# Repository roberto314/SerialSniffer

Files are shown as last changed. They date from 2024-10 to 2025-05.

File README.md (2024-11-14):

# SerialSniffer
A Board to to observe serial communication between two units.

Version 1.0

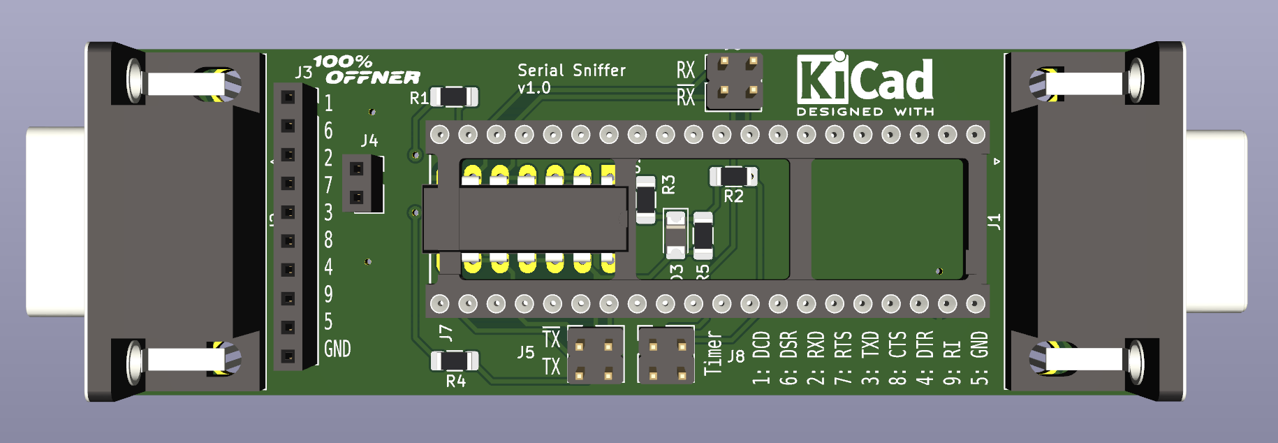
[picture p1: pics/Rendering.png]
kicad Rendering


This is a small PCB with a STM32F401 "blackpill" Board ontop. It can measure the Baudrate with a timer and then switch to listen mode and relay the packets via USB to the host computer.

There are two hardware serial ports on the STM32 and one USB for shell and output.

Firmware is ChibiOS Link: https://www.chibios.org), Version is trunk from ChibiStudio 20. Compilation is done with ChibiStudio 20 on Linux.

### Usage ###

* Connect a USB Cable to the "blackpill" Board,
* Start a terminal (i use picocom - "picocom /dev/ttyACM0")
* press "ENTER" a shell prompt should appear: Serial_Sniffer>
* enter "help" to get a list of all commands
* connect the Jumper J8 (marked "Timer") to one of the channels
* when communication occurs there should be a "Baud: abcd" outpt at the console
* enter the Baudrate with "sbr abcd" and switch on the listeners with "son 1"

There are some Jumpers on the board. J3 and J4 and the solder Jumper on the back JP2 and JP3 lets you connect to different Pins of the DB-9 connector for non-standard pinouts. The Jumper Pin5 is for Ground which is usually on Pin5.

### Used Software and OS ###

* Linux Mint (21.3 cinnamon) (Link: https://linuxmint.com/)
* Sublime Text 3 (Link: https://www.sublimetext.com/)
* Chibi Studio 20 (IDE for ChibiOS) (Link: https://www.chibios.org/dokuwiki/doku.php?id=chibios:products:chibistudio:start)

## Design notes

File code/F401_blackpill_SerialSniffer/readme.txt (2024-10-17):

*****************************************************************************
** ChibiOS/RT port for ARM-Cortex-M4 STM32F407.                            **
*****************************************************************************

** TARGET **

The demo runs on an STM32F411 or STM32F401 blackpill board.
(25MHz Crystal)
Serial Port over USB (also Debug Interface).
Serial 115200 Bd

Build:
Build with eclipse or simply type "make" in the code folder.

-----------------   WORK in Progress

Functions:

Pinout:
PA0  - KEY Button
PA1  - free
PA2  - TX2 (listener 2)
PA3  - RX2 (listener 2)
PA4  - free
PA5  - free
PA6  - free
PA7  - free
PA8  - free
PA9  - TX1 (listener 1)
PA10 - RX1 (listener 1)
PA11 - USD DM (Ostrich)
PA12 - USB DP (Ostrich)
PA13 - SWDIO
PA14 - SWCLK
PA15 - free

PB0  - free
PB1  - free
PB2  - free
PB3  - free
PB4  - free
PB5  - free
PB6  - free
PB7  - free
PB8  - free
PB9  - free
PB10 - free

PB12 - free
PB13 - free
PB14 - free
PB15 - free

PC13 - LED
PC14 - Debug
PC15 - Debug

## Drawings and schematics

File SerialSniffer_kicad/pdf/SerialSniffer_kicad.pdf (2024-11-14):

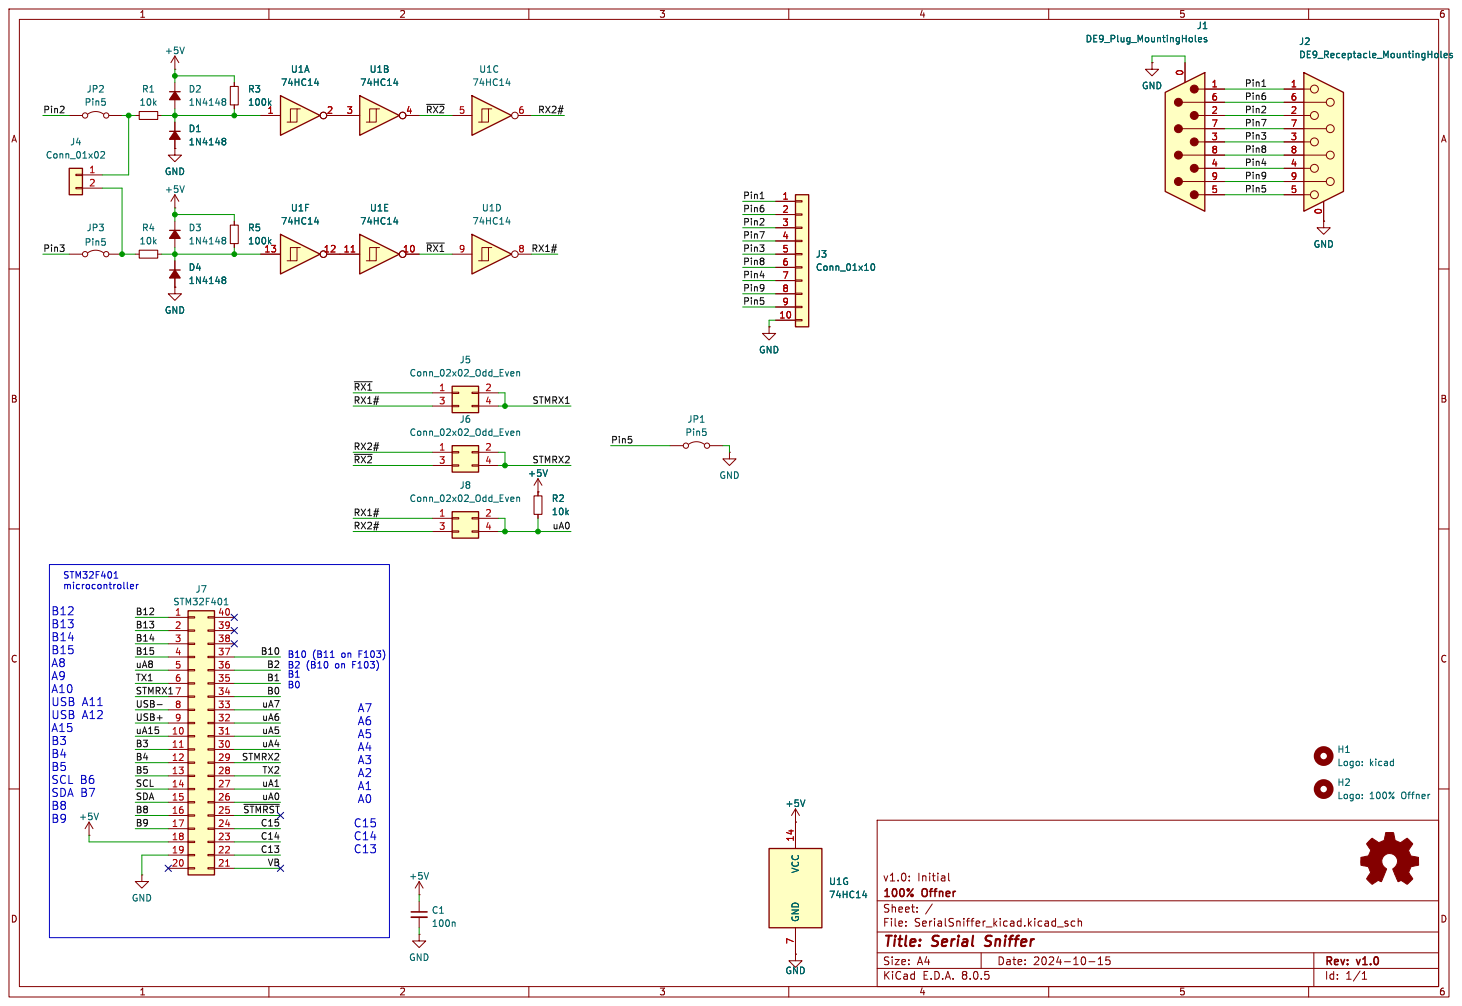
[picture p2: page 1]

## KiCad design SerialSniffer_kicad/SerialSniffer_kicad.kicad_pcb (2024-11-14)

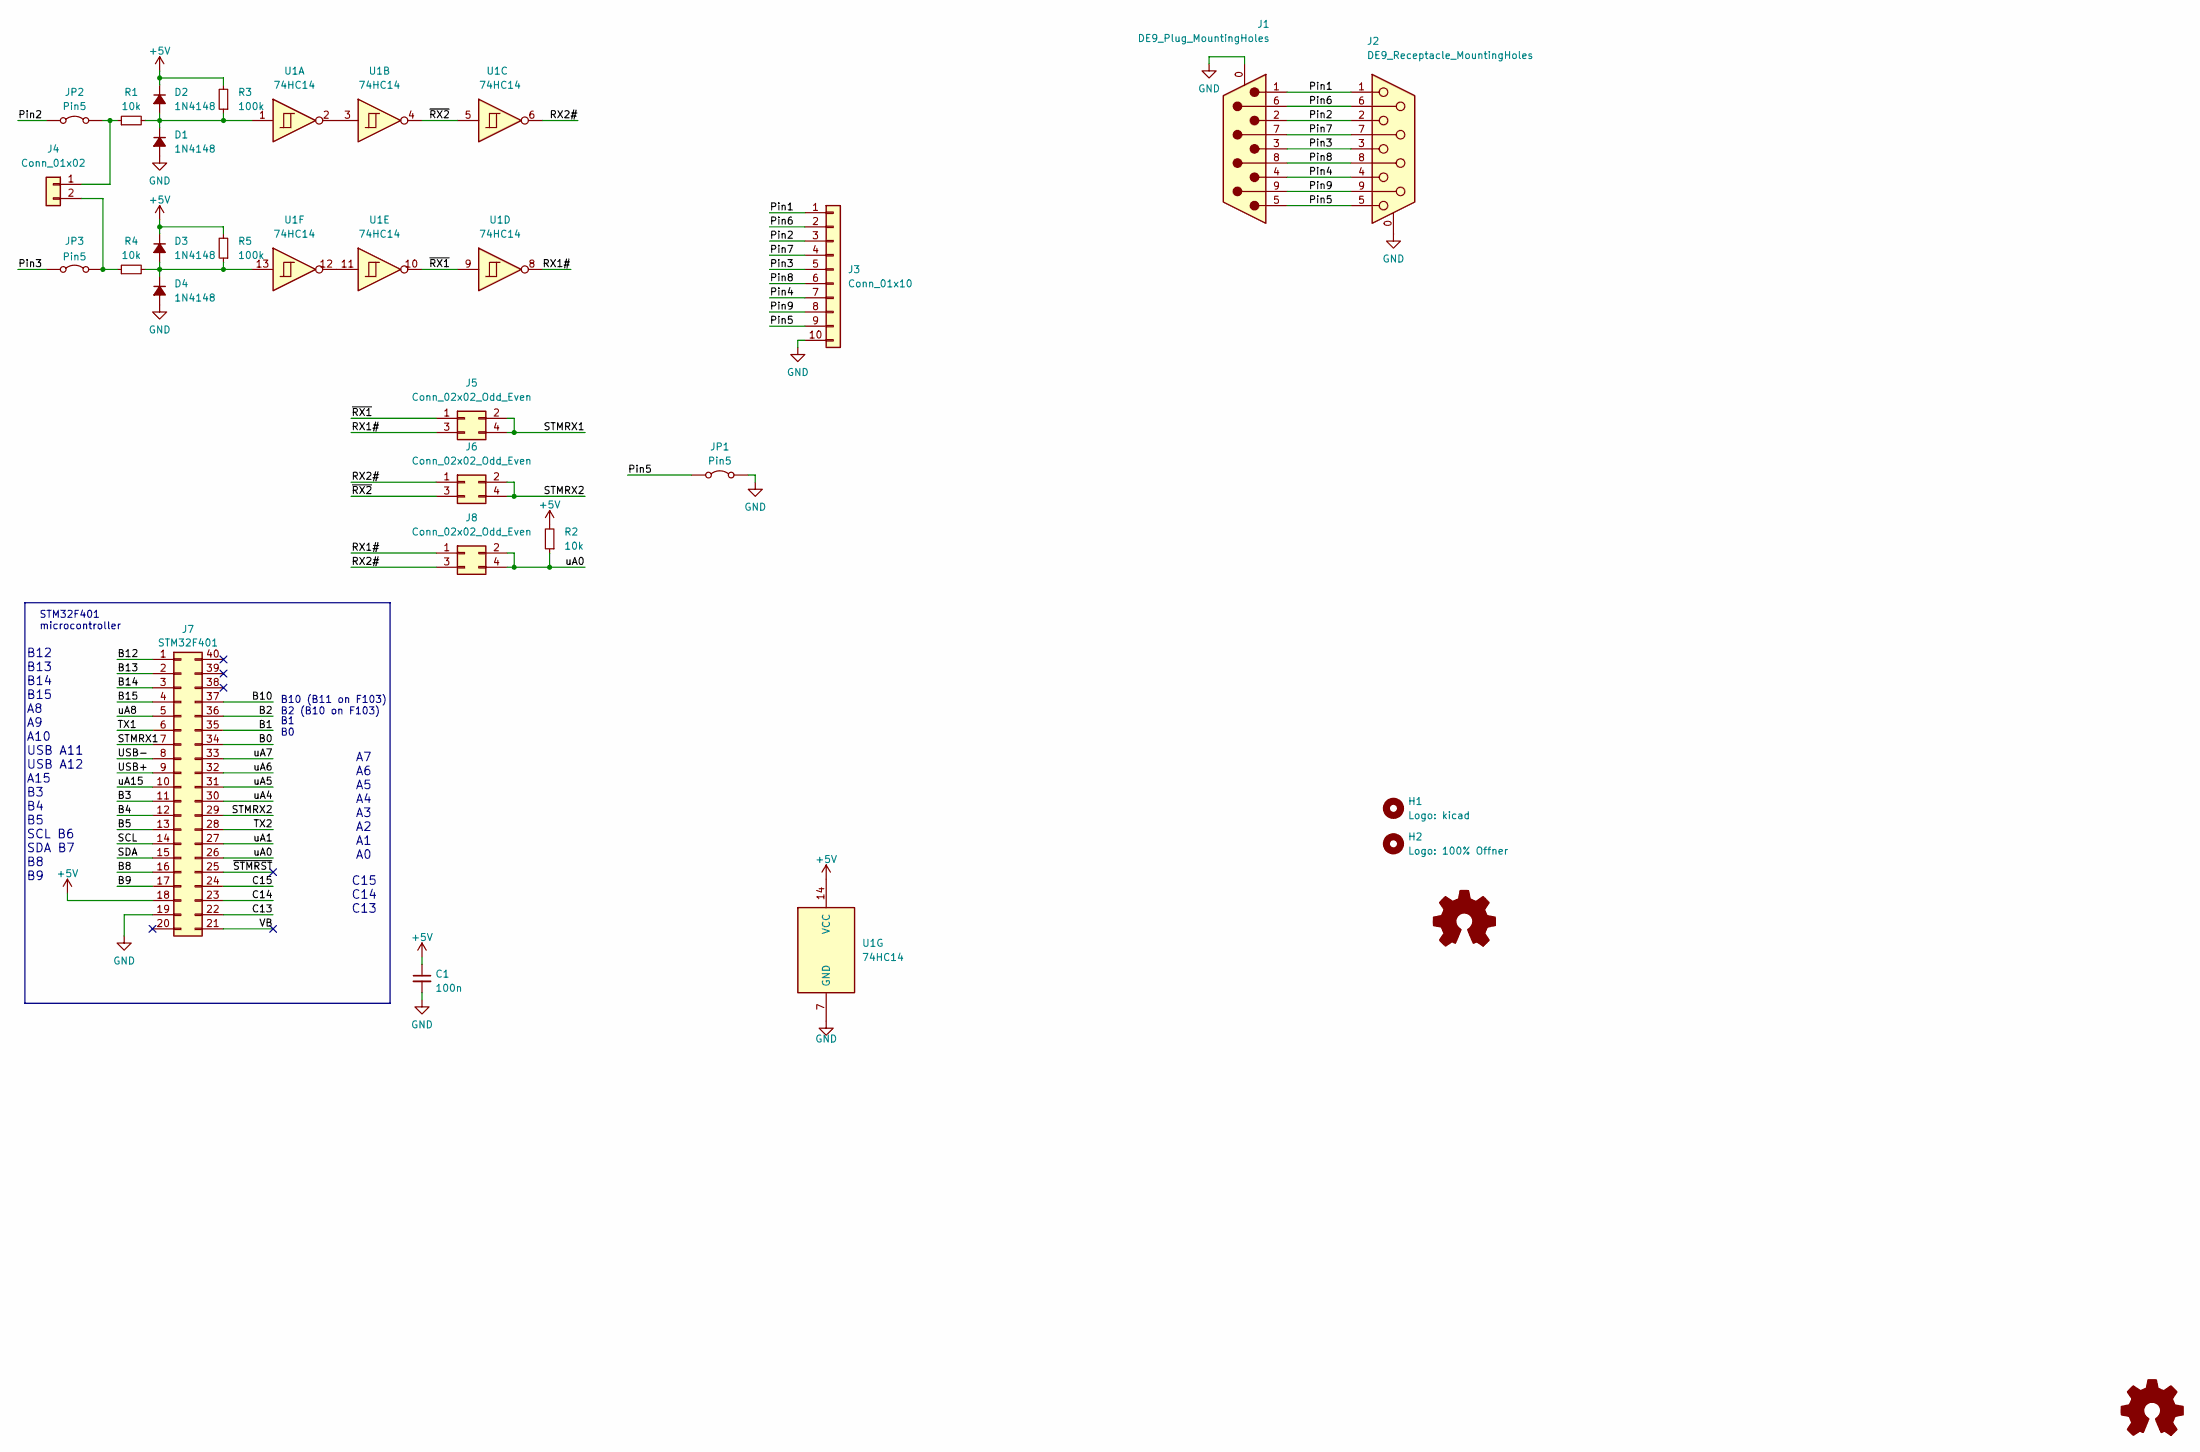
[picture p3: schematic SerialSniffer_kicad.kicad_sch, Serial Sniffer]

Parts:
C1: 100n; C_1206_3216Metric
D1, D2, D3, D4: 1N4148; D_1206_3216Metric_Pad1.42x1.75mm_HandSolder
H1: Logo: kicad; KiCad-Logo2_5mm_SilkScreen
H2: Logo: 100% Offner; Logo_100ProzentOffner_10x2.7mm
J1: DE9_Plug_MountingHoles; DSUB-9_Female_Horizontal_P2.77x2.84mm_EdgePinOffset7.70mm_H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
J2: DE9_Receptacle_MountingHoles; DSUB-9_Male_Horizontal_P2.77x2.84mm_EdgePinOffset7.70mm_Hou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
J3: Conn_01x10; PinSocket_1x10_P2.54mm_Vertical
J4: Conn_01x02; PinSocket_1x02_P2.54mm_Vertical
J5, J6, J8: Conn_02x02_Odd_Even; PinHeader_2x02_P2.54mm_Vertical
J7: STM32F401; DIP-40_W15.24mm_Socket_LongPads
JP1, JP2, JP3: Pin5; SolderJumper-2_P1.3mm_Bridged_RoundedPad1.0x1.5mm
R1, R2, R4: 10k; R_1206_3216Metric_Pad1.30x1.75mm_HandSolder
R3, R5: 100k; R_1206_3216Metric_Pad1.30x1.75mm_HandSolder
U1: 74HC14; DIP-14_W7.62mm_LongPads

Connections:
+5V: C1.1, D2.1 (K), D3.1 (K), J7.18, R2.2, R3.2, R5.2, U1.14 (VCC)
/B0: J7.34
/B1: J7.35
/B2: J7.36
/B3: J7.11
/B4: J7.12
/B5: J7.13
/B8: J7.16
/B9: J7.17
/B10: J7.37
/B12: J7.1
/B13: J7.2
/B14: J7.3
/B15: J7.4
/C13: J7.22
/C14: J7.23
/C15: J7.24
/Pin1: J1.1, J2.1, J3.1
/Pin2: J1.2, J2.2, J3.3, JP2.2 (B)
/Pin3: J1.3, J2.3, J3.5, JP3.2 (B)
/Pin4: J1.4, J2.4, J3.7
/Pin5: J1.5, J2.5, J3.9, JP1.1 (A)
/Pin6: J1.6, J2.6, J3.2
/Pin7: J1.7, J2.7, J3.4
/Pin8: J1.8, J2.8, J3.6
/Pin9: J1.9, J2.9, J3.8
/RX1#: J5.3, J8.1, U1.8
/RX2#: J6.1, J8.3, U1.6
/SCL: J7.14
/SDA: J7.15
/STMRX1: J5.2, J5.4, J7.7
/STMRX2: J6.2, J6.4, J7.29
/TX1: J7.6
/TX2: J7.28
/USB+: J7.9
/USB-: J7.8
/VB: J7.21
/uA0: J7.26, J8.2, J8.4, R2.1
/uA1: J7.27
/uA4: J7.30
/uA5: J7.31
/uA6: J7.32
/uA7: J7.33
/uA8: J7.5
/uA15: J7.10
/~RX1: J5.1, U1.9, U1.10
/~RX2: J6.3, U1.4, U1.5
/~STMRST: J7.25
GND: C1.2, D1.2 (A), D4.2 (A), J1.0 (PAD), J2.0 (PAD), J3.10, J7.19, JP1.2 (B), U1.7 (GND)
unnamed: D1.1 (K), D2.2 (A), R1.2, R3.1, U1.1
unnamed: D3.2 (A), D4.1 (K), R4.2, R5.1, U1.13
unnamed: J4.1, JP2.1 (A), R1.1
unnamed: J4.2, JP3.1 (A), R4.1
unnamed: U1.2, U1.3
unnamed: U1.11, U1.12

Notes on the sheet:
B1 B0
B10 (B11 on F103) B2 (B10 on F103)
A7 A6 A5 A4 A3 A2 A1 A0
B12 B13 B14 B15 A8 A9 A10 USB A11 USB A12 A15 B3 B4 B5 SCL B6 SDA B7 B8 B9
C15 C14 C13
STM32F401 microcontroller

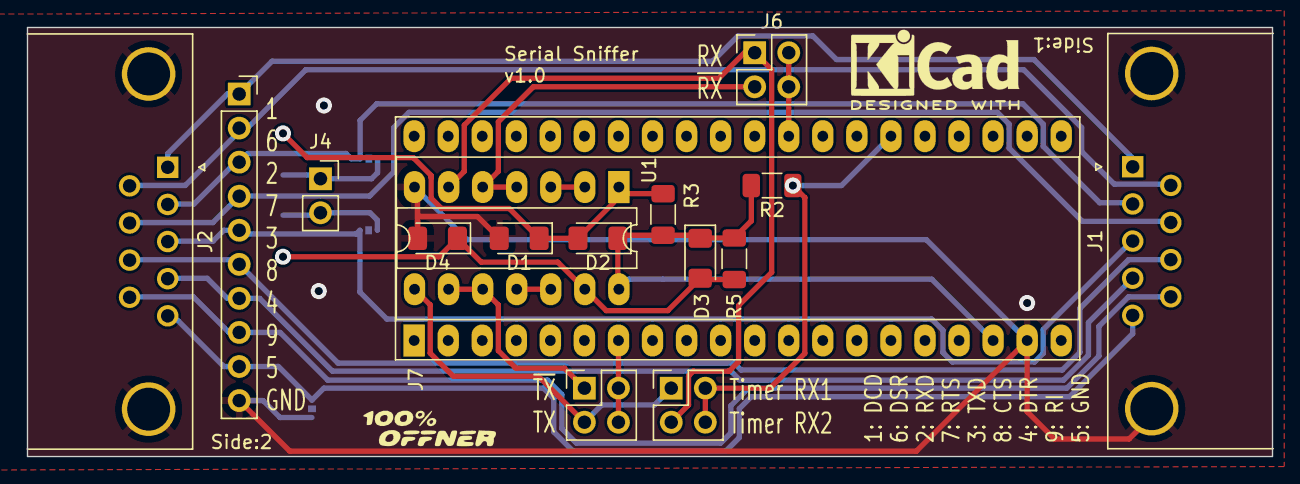
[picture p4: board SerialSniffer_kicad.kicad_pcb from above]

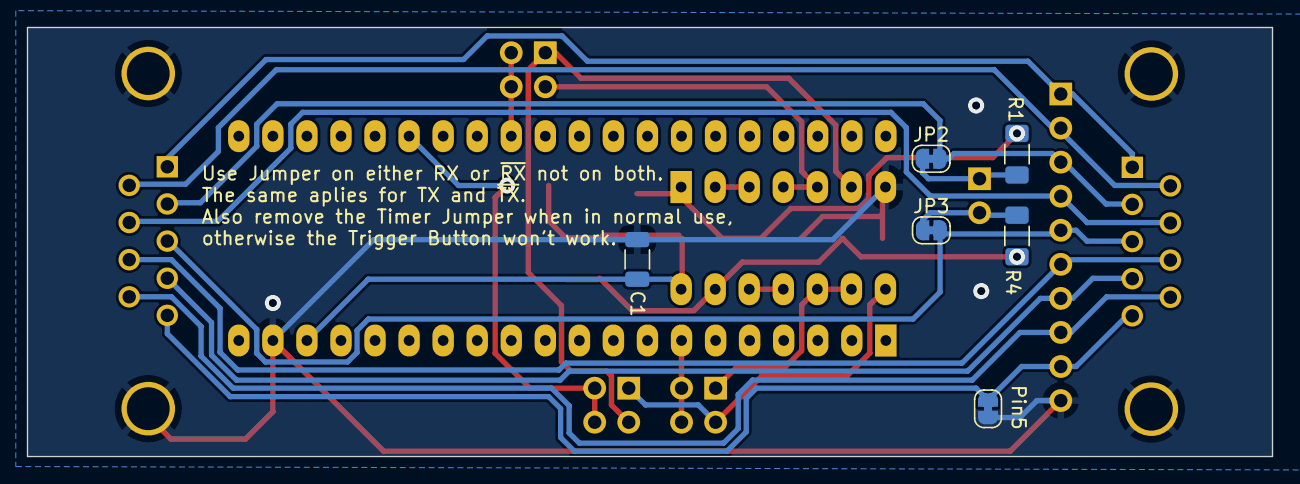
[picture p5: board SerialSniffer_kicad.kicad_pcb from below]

Board: 2 copper layers, 92.9 x 32.0 mm, 24 parts (6 on the bottom side), 24 nets.

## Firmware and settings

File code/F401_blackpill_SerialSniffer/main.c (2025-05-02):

/*
    ChibiOS - Copyright (C) 2006..2018 Giovanni Di Sirio

    Licensed under the Apache License, Version 2.0 (the "License");
    you may not use this file except in compliance with the License.
    You may obtain a copy of the License at

        http://www.apache.org/licenses/LICENSE-2.0

    Unless required by applicable law or agreed to in writing, software
    distributed under the License is distributed on an "AS IS" BASIS,
    WITHOUT WARRANTIES OR CONDITIONS OF ANY KIND, either express or implied.
    See the License for the specific language governing permissions and
    limitations under the License.
*/
#include "main.h"
#include "ch.h"
#include "hal.h"
#include <string.h>
#include <stdlib.h>
#include "portab.h"
#include "shell.h"
#include "chprintf.h"

#include "usbcfg.h"
#include "comm.h"

/*===========================================================================*/
/* Function Prototypes                                                       */
/*===========================================================================*/
void got_char(uint8_t c, uint8_t src);
uint32_t increase_rwcnt(uint32_t cnt);

/*===========================================================================*/
/* Global Variables                                                          */
/*===========================================================================*/
BaseSequentialStream *const shell = (BaseSequentialStream *)&SHELLPORT;
BaseSequentialStream *const dbg = (BaseSequentialStream *)&DEBUGPORT;

#define CLOCKFREQ 10000000UL
#define BUFFSZ 6000 

lst_st ldat[BUFFSZ];                // This is the Buffer
uint32_t write_cnt = 0, read_cnt = 0; // Indizes for Write and Read from Buffer
uint32_t rx_cnt = 0, tx_cnt = 0;
uint16_t flush_timeout = 1000;
uint8_t dump_format = 2, dump_in_progress = 0, first_char = 1;
systime_t fc_timestamp, last_received_char;

uint8_t serstat = 1; // 0: Serial off, Timer On
uint32_t smallest_pulse = 0xFFFF;
icucnt_t last_width1, last_period1;
uint32_t sp_temp;

/*===========================================================================*/
/* Button related code.                                                      */
/*===========================================================================*/

/* Function prototypes needed as the two callbacks call each other.
   there is no way to order the callback without triggering an error. */
static void button_cb(void *arg);
static void vt_cb(virtual_timer_t *vtp, void *p);
static uint8_t btn_second_edge = 0, btn_cnt = 0;

/* Virtual timer. */
static virtual_timer_t vt, vt2;

/* Callback of the virtual timer. */
static void vt_cb(virtual_timer_t *vtp, void *p) { // Timer cb after 50ms (single click)
  (void)vtp;
  (void)p;
  chSysLockFromISR();
  /* Enabling the event and associating the callback. */
  if (btn_second_edge) // The first edge is a negative one, the second a rising one
    palEnableLineEventI(EXTBTN, PAL_EVENT_MODE_RISING_EDGE); // Prepare for release of button
  else
    palEnableLineEventI(EXTBTN, PAL_EVENT_MODE_FALLING_EDGE);
  palSetLineCallbackI(EXTBTN, button_cb, NULL);
  chSysUnlockFromISR();
}

static void vt2_cb(virtual_timer_t *vtp, void *p) { // Timer cb after 200ms (double click)
  (void)vtp;
  (void)p;
  chSysLockFromISR();
  switch (btn_cnt){
  case 1:
    if (btn_second_edge){ // only for the first edge
      //chprintf(dbg, "click long. %d \r\n");
    }
    break;
  case 2:
    //chprintf(dbg, "click once. %d \r\n");
    got_char(' ', 3);
    break;
  default:
    //chprintf(dbg, "click double. %d \r\n");
    break;
  }

  btn_cnt = 0;
  chSysUnlockFromISR();
}
/* Callback associated to the falling or rising edge of the button line. */
static void button_cb(void *arg) {
  (void)arg;
  //palToggleLine(LED);
  if (btn_second_edge){    // next edge
    btn_second_edge = 0;
  }
  else{                  // very first negative going edge or Button released
    btn_second_edge = 1;
    //chprintf(dbg, "click immediately. %d \r\n");
  }
  btn_cnt++;           // count edges
  chSysLockFromISR();
  /* Disabling the event on the line and setting a timer to
     re-enable it. */
  palDisableLineEventI(EXTBTN);
  /* Arming the VT timer to re-enable the event in 50ms. */
  chVTResetI(&vt);
  chVTDoSetI(&vt, TIME_MS2I(50), vt_cb, NULL);
  chVTResetI(&vt2);
  chVTDoSetI(&vt2, TIME_MS2I(200), vt2_cb, NULL);
  chSysUnlockFromISR();
}

/*===========================================================================*/
/* Character Write Function                                                  */
/*===========================================================================*/

void got_char(uint8_t c, uint8_t src){ // This function fills the Ringbuffer
  //int32_t temp;
  //temp = write_cnt-1; // last entry
  last_received_char = TIME_I2MS(chVTGetSystemTime()); // get Timestamp
  if (src == 3){
    chprintf(dbg, "------------------ BREAK @ T[ms]: %06d\r\n", last_received_char);
  }
  else{
    ldat[write_cnt].lastchar = c;
    ldat[write_cnt].src = src;
    ldat[write_cnt].timestamp = last_received_char;
    if ((rx_cnt+tx_cnt) <= 1){
      //first_char = 0;
      chprintf(dbg, "\r\n------------------------- START HERE ------------------------------\r\n");
      fc_timestamp = last_received_char; // very first character
    } 
    write_cnt = increase_rwcnt(write_cnt);
  }
}

/*
 * This callback is invoked when a character is received but the application
 * was not ready to receive it, the character is passed as parameter.
 */
static void rxchar1(UARTDriver *uartp, uint16_t c) {
  (void)uartp;
  (void)c;
  rx_cnt++;
  got_char((uint8_t)c, 1);
}

UARTConfig uart_cfg1 = {
  NULL,
  NULL,
  NULL,
  rxchar1,
  NULL,
  NULL,
  38400,
  0,  // CR1 
  0,  // CR2 
  0   // CR3
};

static void rxchar2(UARTDriver *uartp, uint16_t c) {
  (void)uartp;
  (void)c;
  tx_cnt++;
  got_char((uint8_t)c, 2);
}

UARTConfig uart_cfg2 = {
  NULL,
  NULL,
  NULL,
  rxchar2,
  NULL,
  NULL,
  38400,
  0,  // CR1 
  0,  // CR2 
  0   // CR3
};

/*===========================================================================*/
/* Baudrate Measurement related                                              */
/*===========================================================================*/

static void icuwidthcb1(ICUDriver *icup) { // This gets called every falling edge.

  last_width1 = icuGetWidthX(icup);
  palTogglePad(GPIOC, 14);
  //if (last_width1 < smallest_pulse)
  //  smallest_pulse = last_width1;
}

static void icuperiodcb1(ICUDriver *icup) { // This gets called every rising edge.

  last_period1 = icuGetPeriodX(icup);
  palTogglePad(GPIOC, 15);
  sp_temp = last_period1 - last_width1;
  if (sp_temp < smallest_pulse)
    smallest_pulse = sp_temp;
  //if ((last_period1 - last_width1) < smallest_pulse)
  //  smallest_pulse = (last_period1 - last_width1);
}

ICUConfig icucfg1 = {
  ICU_INPUT_ACTIVE_HIGH,
  CLOCKFREQ,                                    /* 10MHz ICU clock frequency.   */
  icuwidthcb1,
  icuperiodcb1,
  NULL,
  ICU_CHANNEL_1,
  0U,
  0xFFFFFFFFU
};

void flush_buffer(void){
  write_cnt = 0;
  read_cnt = 0;
  memset(ldat, 0, sizeof(ldat));
  chprintf(dbg, "RX Count: %d or 0x%04X\r\n", rx_cnt, rx_cnt);
  chprintf(dbg, "TX Count: %d or 0x%04X\r\n", tx_cnt, tx_cnt);
  chprintf(dbg, "Total Count: %d or 0x%04X\r\n",(tx_cnt+rx_cnt), (tx_cnt+rx_cnt));
  rx_cnt = 0;
  tx_cnt = 0;
}

/*===========================================================================*/
/* Command line related.                                                     */
/*===========================================================================*/

#define SHELL_WA_SIZE   THD_WORKING_AREA_SIZE(2048)

char history_buffer[8*64];
char *completion_buffer[SHELL_MAX_COMPLETIONS];

static const ShellCommand commands[] = {
  {"test",cmd_test},
  {"sbr",cmd_sbr},
  {"son",cmd_son},
  {"format",cmd_format},
  {"flush",cmd_flush},
  {"stt",cmd_stt},
  {NULL, NULL}
};

static const ShellConfig shell_cfg1 = {
  (BaseSequentialStream *)&SHELLPORT,
  commands,
  history_buffer,
  sizeof(history_buffer),
  completion_buffer
};

uint32_t calc_baud(uint32_t time){
  double baudf = 0;
  uint32_t baud, baudu, baudl;
  uint32_t sbr[] = {150,300,600,1200,2400,4800,9600,19200,38400,57600,115200,230400};
  uint8_t idx = 0;
  if (time == 0)
    return 0;
  baudf = (CLOCKFREQ/time);
  baudu = (uint32_t)(baudf * 1.09); // Window is +- 9%
  baudl = (uint32_t)(baudf / 1.09); // Window is +- 9%
  baud = (uint32_t)baudf;
  //chprintf(dbg, "baud: %d, time: %d\r\n", baud, time);
  if (baudu < sbr[0])
    return 0;
  if (baudl > sbr[11])
    return 0xFFFFFFFF;
  for (idx = 0;idx < 12; idx++){
    //chprintf(dbg, "sbrl: %d sbru: %d\r\n", sbrl[idx], sbru[idx]);
    if ((baudl < sbr[idx]) && (baudu > sbr[idx]))
      return sbr[idx];
  }
  return baud;
}

/*
 * Green LED blinker thread, times are in milliseconds.
 */
static THD_WORKING_AREA(waThread1, 128);
static THD_FUNCTION(Thread1, arg) {

  (void)arg;
  chRegSetThreadName("blinker");
  while (true) {
    systime_t time;
    time = serusbcfg1.usbp->state == USB_ACTIVE ? 250 : 500;
    palClearPad(GPIOC, 13);
    chThdSleepMilliseconds(time);
    palSetPad(GPIOC, 13);
    chThdSleepMilliseconds(time);
    if (smallest_pulse < 65535){
      //chprintf(dbg, "Time: %d \r\n", smallest_pulse);
      chprintf(dbg, "Baud: %d \r\n", calc_baud(smallest_pulse));
      smallest_pulse = 0xFFFF;
    }
    //chprintf(dbg, "LastWidth: %d \r\n", last_width1);
    //chprintf(dbg, "LastPeriod: %d \r\n", last_period1);
//    count++;
//    if (count == 10){
//      count = 0;
//      smallest_pulse = 0xFFFF;
//    }
  }
}

void safe_print(uint8_t c){  // print only printable characters
  if ((c > 0x1F) && (c < 128))
    chprintf(dbg, "%c", c);
  else
    chprintf(dbg, "%c",'.');    
}

uint32_t increase_rwcnt(uint32_t cnt){
  cnt++;
  if (cnt >= BUFFSZ) cnt = 0; // check for oerflow
  return cnt;
}

int32_t get_count(void){
/* Data in Array (c: Character, 1,2: Source, t: Timestamp)
* c2tc2tc2tc2tc1tc1tc2t
* Dump this  |
*        make CR
*            |Dump|
*              make CR
*              wait until a change in source or a timeout happens
*/
  uint32_t temp_cnt = read_cnt;
  uint8_t src, next;
  if (ldat[temp_cnt].src == 0) return -2; // no more data in array
  while (1) {
    src = ldat[temp_cnt].src;
    temp_cnt = increase_rwcnt(temp_cnt);
    next = ldat[temp_cnt].src;
    if (src != next){ // we have a change in source
      if (next == 0) return -1; // block not finished, wait for timeout
      else return (temp_cnt - read_cnt); // block is finished
    } 
  }
  //chprintf(dbg, "i: %d, SRC: %d NXT: %d\r\n", i, src, next);
  return -2;
}

void dump_data_0(uint32_t cnt){
  uint32_t i;
  uint8_t ch, src;
  systime_t tm, dt;

  src = ldat[read_cnt].src;
  chprintf(dbg, "%d->%d cnt: %d \r\n", src, (src==1?2:1), cnt);
  for (i=0;i<cnt;i++){ // go through all the characters
    ch = ldat[read_cnt].lastchar;
    src = ldat[read_cnt].src;
    ldat[read_cnt].src = 0; // delete for next round
    tm = ldat[read_cnt].timestamp - fc_timestamp; // tm starts at zero
    dt = ldat[read_cnt].timestamp - ldat[(read_cnt-1)].timestamp; // time difference 
    if (tm)
      chprintf(dbg, "%02X T: %06d dT: %04d\r\n", ch, tm, dt);
    else
      chprintf(dbg, "%02X T: %06d dT: ----\r\n", ch, tm);
    read_cnt = increase_rwcnt(read_cnt);
  }
  //chprintf(dbg, "\r\n");
  return;
}

void dump_data_1(uint32_t cnt){
  uint32_t i;
  uint8_t ch, src;
  systime_t tm;

  src = ldat[read_cnt].src;
  tm = ldat[read_cnt].timestamp - fc_timestamp; // tm starts at zero
  chprintf(dbg, "%d->%d cnt: %d T: %06d\r\n", src, (src==1?2:1), cnt, tm);
  for (i=0;i<cnt;i++){ // go through all the characters
    ch = ldat[read_cnt].lastchar;
    ldat[read_cnt].src = 0; // delete for next round
    read_cnt = increase_rwcnt(read_cnt);

    if ((i%16 == 0) && (i>0)) chprintf(dbg, "\r\n");
    chprintf(dbg, "%02X ", ch);
  }
  chprintf(dbg, "\r\n");
  return;
}

void dump_data_2(uint32_t cnt){
  uint32_t i, j, line, width = 0;
  uint8_t ch, src;
  uint8_t ascii[16];
  systime_t tm;

  src = ldat[read_cnt].src;
  tm = ldat[read_cnt].timestamp - fc_timestamp; // tm starts at zero
  chprintf(dbg, "%d->%d cnt: %d T: %06d\r\n", src, (src==1?2:1), cnt, tm);
  for (line=0; line < cnt;line+=16){
    width = 0;
    // print HEX here
    for (i=0;i<16;i++){ // print max 16 char per line
      if ((i+line) >= cnt){
        chprintf(dbg, "   "); // fill the space
      }
      else{
        ch = ldat[read_cnt].lastchar;
        ascii[width] = ch;
        ldat[read_cnt].src = 0; // delete for next round
        read_cnt = increase_rwcnt(read_cnt);
        chprintf(dbg, "%02X ", ch);
        width++;
      }
    }
    chprintf(dbg, " | "); // make separator
    // print ASCII here
    for (j=0;j<width;j++){ // print ASCII
      safe_print(ascii[j]);
    }
    chprintf(dbg, "\r\n");
  } // end Line   
  return;
}

void check_data(void){       // Thread, every 50ms
  uint32_t cnt;
  int32_t temp;

  if ((rx_cnt+tx_cnt) == 0) return; // nothing to print
  
  temp = get_count();
  if (temp == -2) return; // no data
  if (temp == -1){
    if (TIME_I2MS(chVTGetSystemTime()) - last_received_char > flush_timeout){
      cnt = write_cnt - read_cnt; // dump everything
    }
    else return;
  }
  else cnt = (uint32_t)temp;
  //chprintf(dbg, "%d->%d c: %d OLD: %d LDAT: %d\r\n", src, dest, cnt, read_cnt, write_cnt);
  switch(dump_format){
  case 0:
    dump_data_0(cnt);
    break;
  case 1:
    dump_data_1(cnt);
    break;
  case 2:
    dump_data_2(cnt);
    break;
  default:
    break;
  }
}

static THD_WORKING_AREA(waListener3, 128);
static THD_FUNCTION(Listener3, arg) { // This Thread listens to the onboard Button to make a "Mark" in the Logging,
                                      // It also checks if data is to output

  (void)arg;
  static uint8_t disable = 0;
  chRegSetThreadName("listener3");
  while (true) {
    check_data();
    chThdSleepMilliseconds(50);
  }
}

/*
 * Application entry point.
 */
int main(void) {
  thread_t *shelltp = NULL;
  event_listener_t shell_el;

  /*
   * System initializations.
   * - HAL initialization, this also initializes the configured device drivers
   *   and performs the board-specific initializations.
   * - Kernel initialization, the main() function becomes a thread and the
   *   RTOS is active.
   */
  halInit();
  chSysInit();

  palSetPadMode(GPIOC, 13, PAL_MODE_OUTPUT_PUSHPULL ); // LED
  palSetPadMode(GPIOC, 14, PAL_MODE_OUTPUT_PUSHPULL ); // Debug
  palSetPadMode(GPIOC, 15, PAL_MODE_OUTPUT_PUSHPULL ); // Debug
  palSetLineMode(EXTBTN, PAL_MODE_INPUT_PULLUP); // Button
  /* Enabling the event and associating the callback. */
  palEnableLineEvent(EXTBTN, PAL_EVENT_MODE_FALLING_EDGE);
  palSetLineCallback(EXTBTN, button_cb, NULL);

  sduObjectInit(&SHELLPORT);
  sduStart(&SHELLPORT, &serusbcfg1);

  usbDisconnectBus(serusbcfg1.usbp);
  chThdSleepMilliseconds(1500);
  usbStart(serusbcfg1.usbp, &usbcfg);
  usbConnectBus(serusbcfg1.usbp);

  //chprintf(dbg, "\r\nSerial Sniffer Programmer: %i.%i \r\nSystem started. (Shell)\r\n", VMAJOR, VMINOR);
  if (serstat){
    //palSetPadMode(GPIOA, 2, PAL_MODE_ALTERNATE(7));  // TX2
    palSetPadMode(GPIOA, 3, PAL_MODE_ALTERNATE(7));  // RX2
    //palSetPadMode(GPIOA, 9, PAL_MODE_ALTERNATE(7));  // TX1
    palSetPadMode(GPIOA, 10, PAL_MODE_ALTERNATE(7)); // RX1
    uartStart(&UARTD1, &uart_cfg1);
    uartStart(&UARTD2, &uart_cfg2);
    flush_buffer();
  }
  else{
    palSetPadMode(GPIOA, 0, PAL_MODE_ALTERNATE(1));  // TIM2/1
    //palSetPadMode(GPIOA, 3, PAL_MODE_ALTERNATE(3));  // TIM9/2
    //palSetPadMode(GPIOA, 10, PAL_MODE_ALTERNATE(1)); // TIM1/3
    icuStart(&ICUD2, &icucfg1);
    icuStartCapture(&ICUD2);
    icuEnableNotifications(&ICUD2);
  }
  /*
   * Shell manager initialization.
   * Event zero is shell exit.
   */
  shellInit();
  chEvtRegister(&shell_terminated, &shell_el, 0);
  chThdCreateStatic(waThread1, sizeof(waThread1), NORMALPRIO, Thread1, NULL);
  chThdCreateStatic(waListener3, sizeof(waListener3), NORMALPRIO, Listener3, NULL);
  /*
   * Normal main() thread activity, in this demo it does nothing except
   * sleeping in a loop and check the button state.
   */
  while (true) {
#if USB_SHELL == 1
    if (SHELLPORT.config->usbp->state == USB_ACTIVE) {
      /* Starting shells.*/
      if (shelltp == NULL) {
        shelltp = chThdCreateFromHeap(NULL, SHELL_WA_SIZE,
                                       "shell1", NORMALPRIO + 1,
                                       shellThread, (void *)&shell_cfg1);
      }
    //chThdWait(shelltp);               /* Waiting termination.             */
    chEvtWaitAny(EVENT_MASK(0));
    if (chThdTerminatedX(shelltp)) {
      chThdRelease(shelltp);
      shelltp = NULL;
    }
#else
    if (!shelltp)
      shelltp = chThdCreateFromHeap(NULL, SHELL_WA_SIZE,
                                    "shell", NORMALPRIO + 1,
                                    shellThread, (void *)&shell_cfg1);
    else if (chThdTerminatedX(shelltp)) {
      chThdRelease(shelltp);    /* Recovers memory of the previous shell.   */
      shelltp = NULL;           /* Triggers spawning of a new shell.        */
    }
#endif
    /* Waiting for an exit event then freeing terminated shells.*/
    }
    else{
      chThdSleepMilliseconds(1000);
    }
  }
}

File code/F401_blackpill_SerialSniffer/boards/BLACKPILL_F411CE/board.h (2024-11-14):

/*
    ChibiOS - Copyright (C) 2006..2020 Giovanni Di Sirio

    Licensed under the Apache License, Version 2.0 (the "License");
    you may not use this file except in compliance with the License.
    You may obtain a copy of the License at

        http://www.apache.org/licenses/LICENSE-2.0

    Unless required by applicable law or agreed to in writing, software
    distributed under the License is distributed on an "AS IS" BASIS,
    WITHOUT WARRANTIES OR CONDITIONS OF ANY KIND, either express or implied.
    See the License for the specific language governing permissions and
    limitations under the License.
*/

/*
 * This file has been automatically generated using ChibiStudio board
 * generator plugin. Do not edit manually.
 */

#ifndef BOARD_H
#define BOARD_H

/*===========================================================================*/
/* Driver constants.                                                         */
/*===========================================================================*/

/*
 * Setup for STM32 Blackpill-F411CE board.
 */

/*
 * Board identifier.
 */
#define BOARD_BLCKPILL_F411CE
#define BOARD_NAME                  "STM32 Blackpill-F411CE"

/*
 * Board oscillators-related settings.
 * NOTE: LSE not fitted.
 */
#if !defined(STM32_LSECLK)
#define STM32_LSECLK                0U
#endif

#if !defined(STM32_HSECLK)
#define STM32_HSECLK                25000000U
#endif

/*
 * Board voltages.
 * Required for performance limits calculation.
 */
#define STM32_VDD                   300U

/*
 * MCU type as defined in the ST header.
 */
#define STM32F411xE

/*
 * IO pins assignments.
 */
#define GPIOA_ARD_A0                0U
#define GPIOA_ADC1_IN0              0U
#define GPIOA_ARD_A1                1U
#define GPIOA_ADC1_IN1              1U
#define GPIOA_ARD_D1                2U
#define GPIOA_USART2_TX             2U
#define GPIOA_ARD_D0                3U
#define GPIOA_USART2_RX             3U
#define GPIOA_ARD_A2                4U
#define GPIOA_ADC1_IN4              4U
#define GPIOA_LED_GREEN             5U
#define GPIOA_ARD_D13               5U
#define GPIOA_ARD_D12               6U
#define GPIOA_ARD_D11               7U
#define GPIOA_ARD_D7                8U
#define GPIOA_ARD_D8                9U
#define GPIOA_ARD_D2                10U
#define GPIOA_OTG_FS_DM             11U
#define GPIOA_OTG_FS_DP             12U
#define GPIOA_SWDIO                 13U
#define GPIOA_SWCLK                 14U
#define GPIOA_PIN15                 15U

#define GPIOB_ARD_A3                0U
#define GPIOB_ADC1_IN8              0U
#define GPIOB_PIN1                  1U
#define GPIOB_PIN2                  2U
#define GPIOB_SWO                   3U
#define GPIOB_ARD_D3                3U
#define GPIOB_ARD_D5                4U
#define GPIOB_ARD_D4                5U
#define GPIOB_ARD_D10               6U
#define GPIOB_PIN7                  7U
#define GPIOB_ARD_D15               8U
#define GPIOB_ARD_D14               9U
#define GPIOB_ARD_D6                10U
#define GPIOB_PIN11                 11U
#define GPIOB_PIN12                 12U
#define GPIOB_PIN13                 13U
#define GPIOB_PIN14                 14U
#define GPIOB_PIN15                 15U

#define GPIOC_ARD_A5                0U
#define GPIOC_ADC1_IN10             0U
#define GPIOC_ARD_A4                1U
#define GPIOC_ADC1_IN11             1U
#define GPIOC_PIN2                  2U
#define GPIOC_PIN3                  3U
#define GPIOC_PIN4                  4U
#define GPIOC_PIN5                  5U
#define GPIOC_PIN6                  6U
#define GPIOC_ARD_D9                7U
#define GPIOC_PIN8                  8U
#define GPIOC_PIN9                  9U
#define GPIOC_PIN10                 10U
#define GPIOC_PIN11                 11U
#define GPIOC_PIN12                 12U
#define GPIOC_LED                   13U
#define GPIOC_OSC32_IN              14U
#define GPIOC_OSC32_OUT             15U

#define GPIOD_PIN0                  0U
#define GPIOD_PIN1                  1U
#define GPIOD_PIN2                  2U
#define GPIOD_PIN3                  3U
#define GPIOD_PIN4                  4U
#define GPIOD_PIN5                  5U
#define GPIOD_PIN6                  6U
#define GPIOD_PIN7                  7U
#define GPIOD_PIN8                  8U
#define GPIOD_PIN9                  9U
#define GPIOD_PIN10                 10U
#define GPIOD_PIN11                 11U
#define GPIOD_PIN12                 12U
#define GPIOD_PIN13                 13U
#define GPIOD_PIN14                 14U
#define GPIOD_PIN15                 15U
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

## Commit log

2024-11-14 new code
    [SerialSniffer_kicad.kicad_pcb]
2025-05-02 new code, bugfixed, should work
    [comm.c, halconf.h, main.c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]
